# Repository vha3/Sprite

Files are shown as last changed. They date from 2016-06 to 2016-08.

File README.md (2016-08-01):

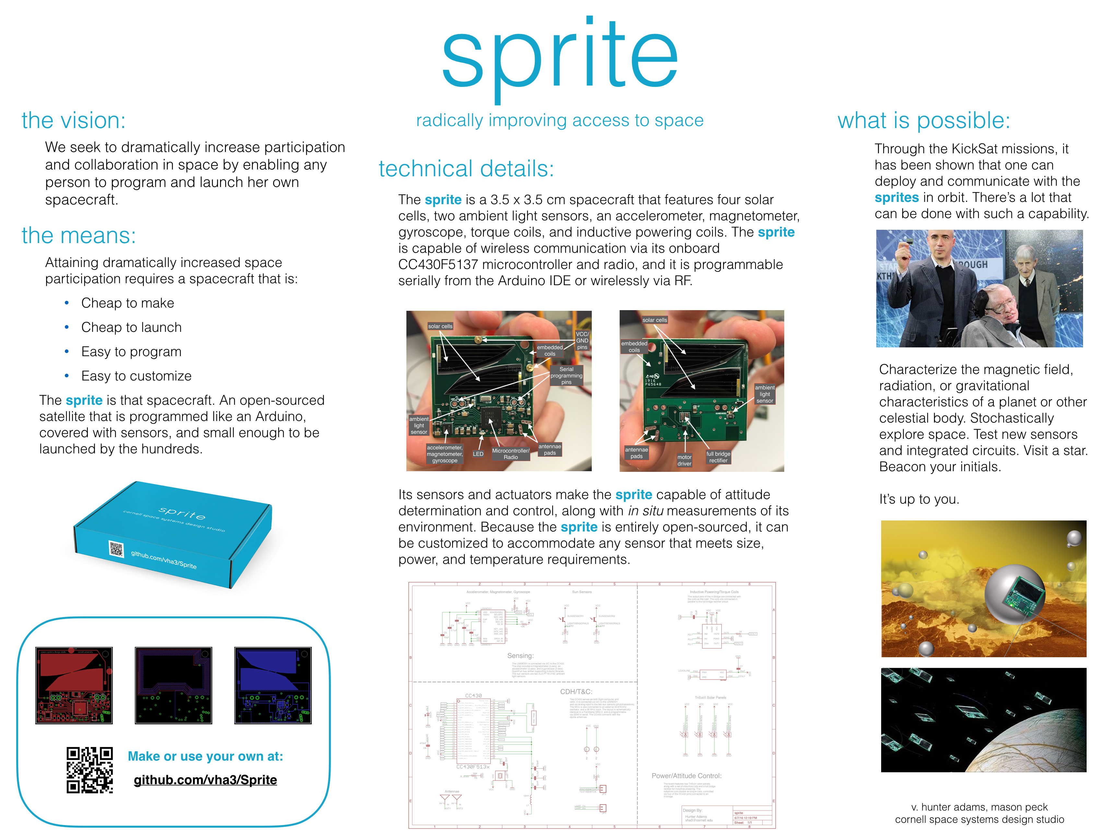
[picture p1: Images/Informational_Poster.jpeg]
My image

 The folders above include everything that you need to start using a newly purchased Sprite or to make one of your own.

 All necessary prototyping materials for programming the Sprite are included in the Sprite development kit. For those that bought or made a Sprite independently, a DigiKey cart is provided below that includes all necessary materials.

http://www.digikey.com/short/3zwh0t

##Just Bought a Sprite?
See the Sprite User's Manual in the main repository above. The manual will walk you through software installation and wiring your Sprite for programming. The Demo Software folder contains a number of Arduino sketches that exercise the Sprite's various sensors and actuators. The ReadMe within the Demo Software folder links to the panStamp example sketches folder, which contains a number more Arduino sketches that will work on the Sprite.

##Making Your Own Sprite?
The above folders contain all of the necessary files and information for having your own Sprite made by a board house. Download this repo, and send a zipped file containing the Gerbers, BOM and CPL, and the images to any board house (request a half-width board, if you intend for it to be used with the Sprite mothership deployer). You may also be interested in downloading the Eagle Cad board and schematic files to customize your own board. Both of these can be found in the Eagle folder.

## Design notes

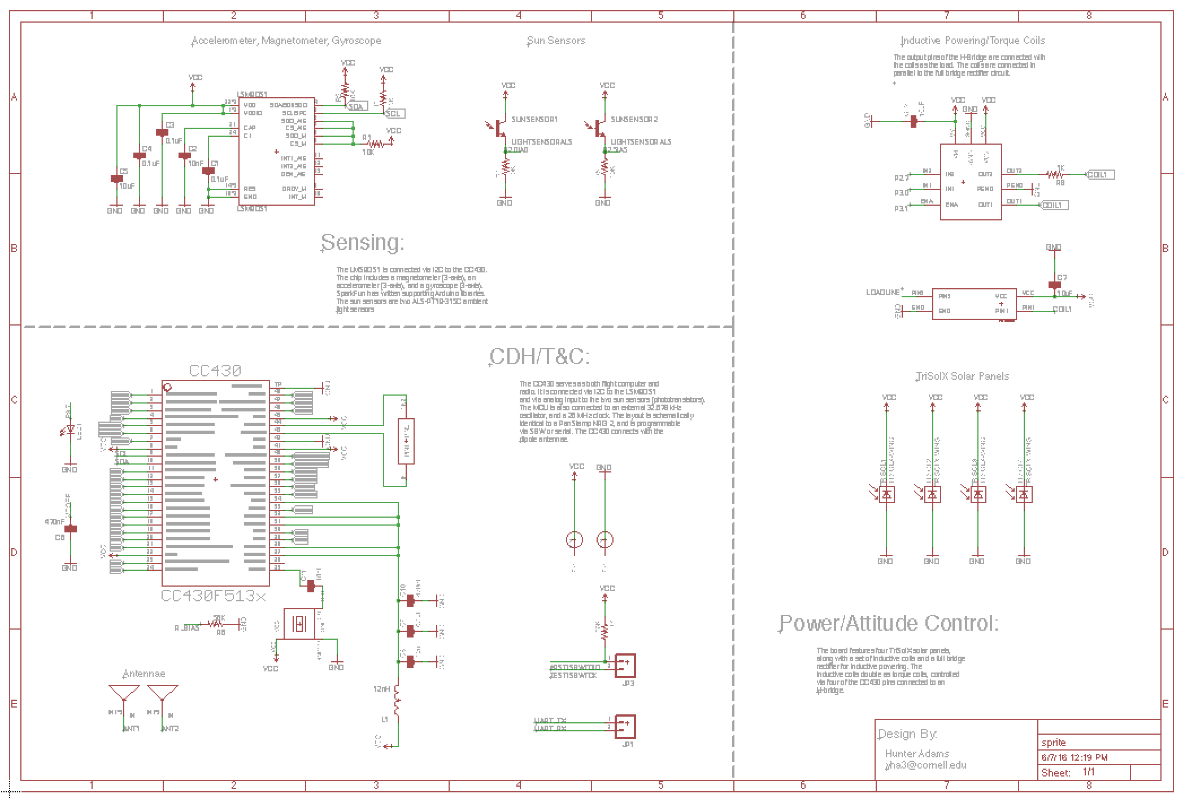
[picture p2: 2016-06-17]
Images/SCHEMATIC.png

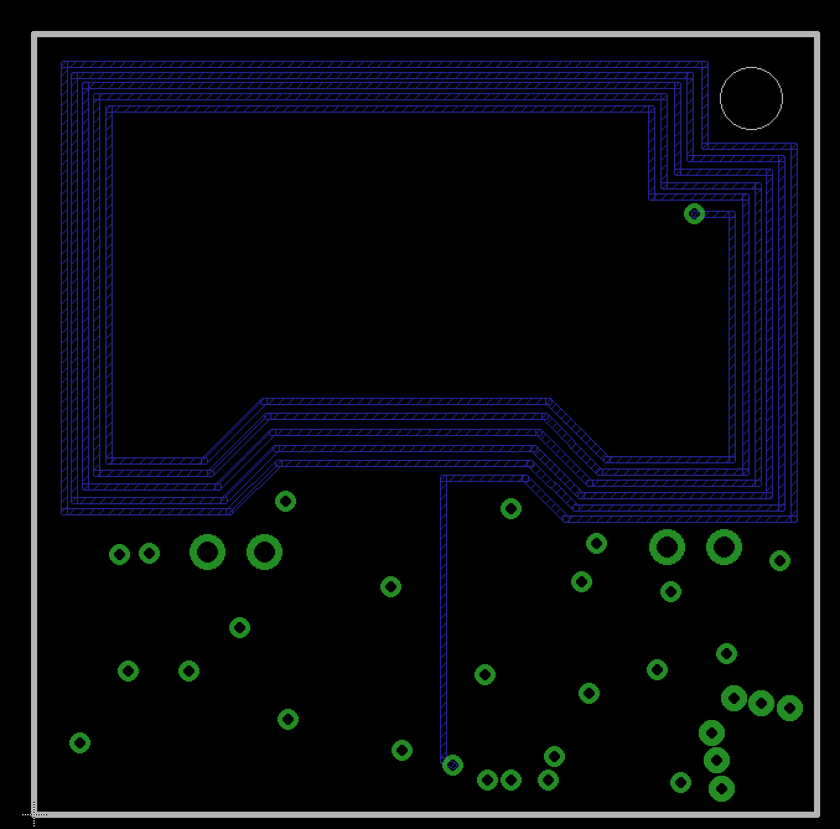
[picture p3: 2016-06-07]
Images/LAYER2.png

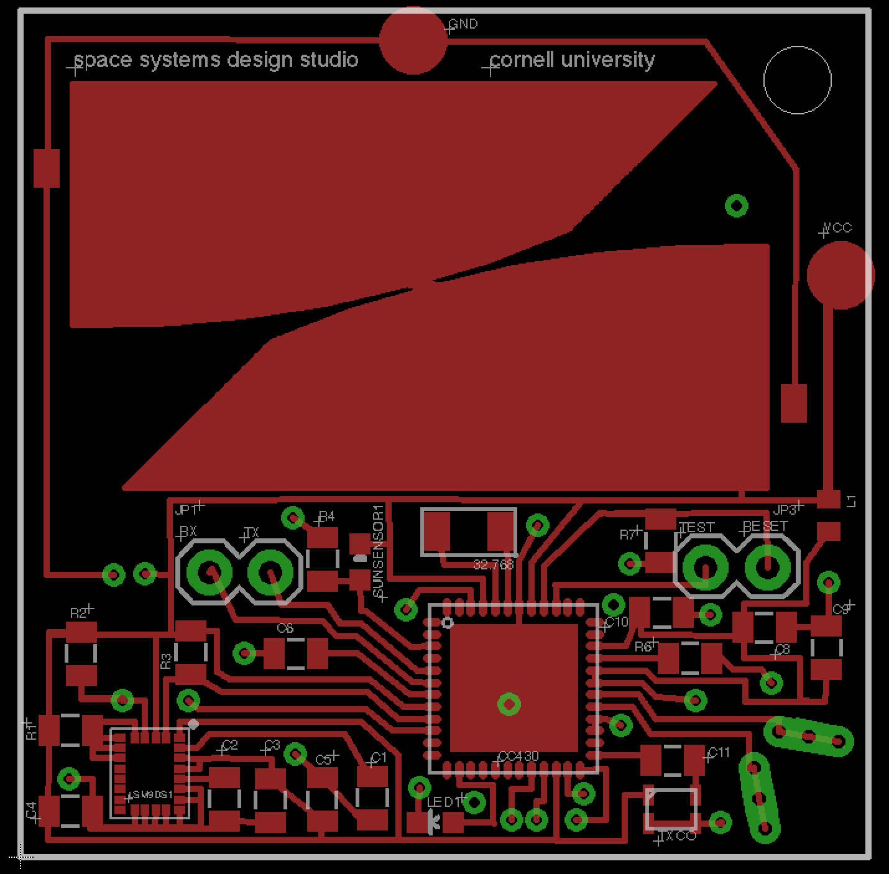
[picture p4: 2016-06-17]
Images/TOP.png

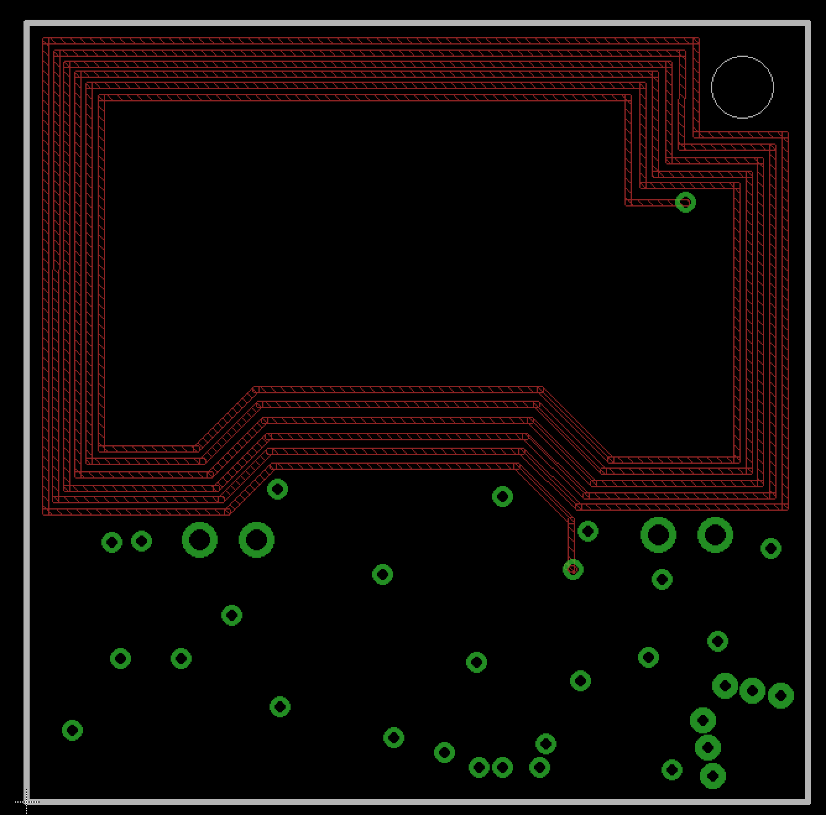
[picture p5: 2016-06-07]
Images/LAYER3.png

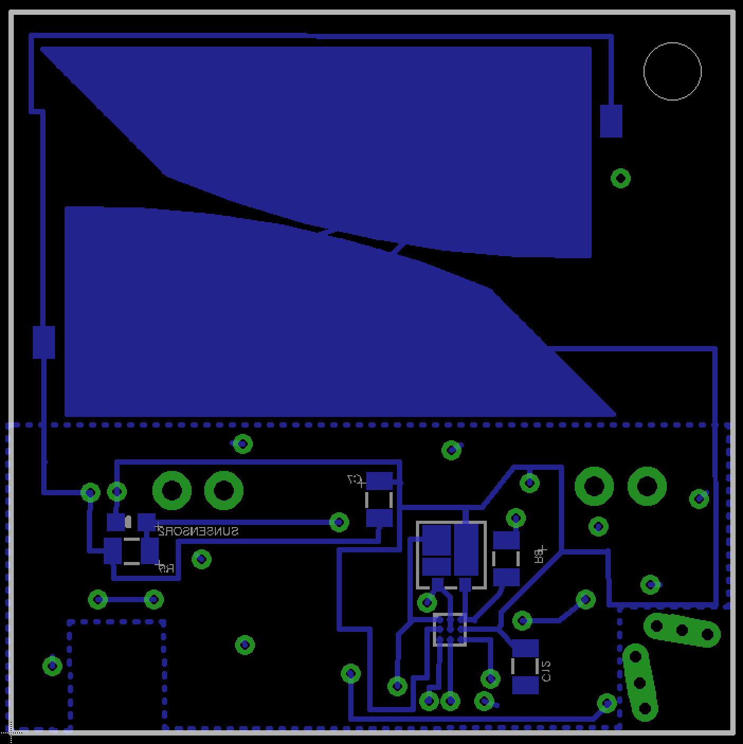
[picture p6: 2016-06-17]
Images/BOTTOM.png

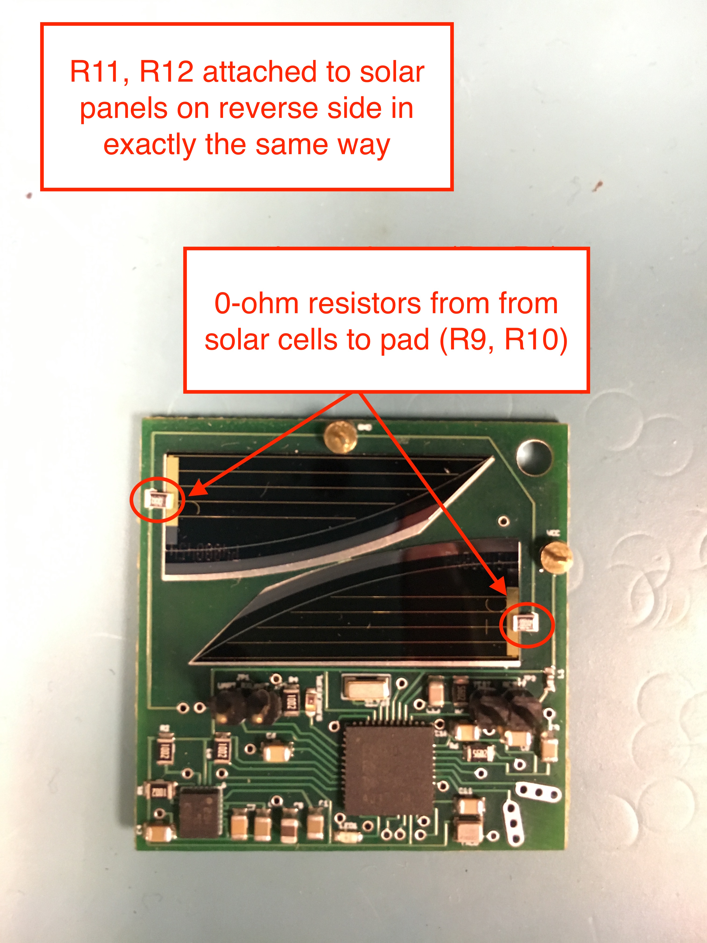
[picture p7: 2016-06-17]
Images/Image.JPG

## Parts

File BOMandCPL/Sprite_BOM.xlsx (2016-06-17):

 | Sprite Chipsat
 | Hunter Adams
 | vha3@cornell.edu
Qty | Value | Device | Package | Parts | Description | Digikey P/N | Manufacturer P/N | Manufacturer
1 | Green | LED0603 | LED-0603 | LED1 | LEDs | 475-2709-1-ND | LG L29K-G2J1-24-Z | OSRAM Opto Semiconductors Inc. (http://www.digikey.com/Suppliers/us/Osram.page?lang=en)
2 | N/A | M02PTH | 1X02 | JP1, JP3 | Header 2 | DNP | DNP | DNP
1 | 26 MHz | TCXO_7Z | TXC_7Z | TXCO | RF oscillator | 887-1622-1-ND | 7Z-26.000MDG-T | TXC Corporation
4 | 0.1uF | CAP0805 | 805 | C1, C3, C4, C9 | Capacitor | 478-3352-2-ND | 08055C104JAT2A | AVX Corp.
5 | 10K | RESISTOR0805 | 805 | R1, R2, R3, R4, R5 | Resistor | 311-10.0KCRTR-ND | RC0805FR-0710KL | Yageo
3 | 10nF | CAP0805 | 805 | C2, C8, C11 | Capacitor | 478-1383-2-ND | 08055C103KAT2A | AVX Corp.
3 | 10uF | CAP0805 | 805 | C5, C7, C12 | Capacitor | 478-5167-2-ND | 0805ZD106KAT2A | AVX Corp.
1 | 12nH | INDUCTOR0402 | C0402 | L1 | Inductors | 553-2319-2-ND | PE-0402CC120JTT | Pulse Electronics Corp.
1 | 1K | RESISTOR0805-RES | 805 | R8 | Resistor | 311-1.0KARCT-ND | RC0805JR-071KL | Yageo
2 | 470nF | CAP0805 | 805 | C6, C10 | Capacitor | 478-1403-2-ND | 0805YC474KAT2A | AVX Corp.
2 | 56K | RESISTOR0805-RES | 805 | R6, R7 | Resistor | 311-56.0KCRTR-ND | RC0805FR-0756KL | Yageo
2 | ANTENNA | ANTENNA | ANTENNA | ANTENNA1, ANTENNA2 | Antennae | DNP | DNP | DNP
1 | N/A | CC430F513X---RGZ48 | RGZ48 | CC430 | ***CC430F513X***RGZ48 ** | CC430F5137IRGZR | CC430F5137IRGZR | Texas Instruments
2 | N/A | LIGHTSENSORALS | ALS-PT19 | SUNSENSOR1, SUNSENSOR2 | Ambient Light Sensor | 1080-1244-1-ND | ALS-PT19-315C/L177/TR8 | Everlight Electronics Co. Ltd
1 | N/A | LSM9DS1 | LGA24-8X4 | LSM9DS1 | LSM9DS1 3D accelerometer, gyroscope & magnetometer | 497-14946-1-ND | LSM9DS1TR | STMicroelectronics
1 | N/A | LV8417CS | LV8417CS | H-BRIDGE | H-bridge integrated circuit | LV8417CS-TE-L-HOSCT-ND | LV8417CS-TE-L-H | ON Semiconductor
1 | N/A | NSR1030QMUTAG | NSR1030QMUTAG | RECTIFIER | Full bridge rectifier integrated circuit | NSR1030QMUTAGOSCT-ND | NSR1030QMUTAG | ON Semiconductor
1 | 32.768 KHz | SPRITECRYSTALSPRITECRYSTAL | SPRITECRYSTAL | 32KHZ | Oscillator | 478-5428-1-ND | ST3215SB32768H5HPWAA | AVX Corp./Kyocera Corp.
2 | N/A | SPRITE_PIN | SPRITE_PIN | GNDPIN, VCCPIN | Pins | ED1088CT-ND | 1508-0-57-15-00-00-03-0 | Mill-Max Manufacturing Corp.
4 | N/A | TRISOLX-WING | TRISOLX-T01 | TRISOL1, TRISOL2, TRISOL3, TRISOL4 | Solar Cells | Provided by customer | Provided by customer | Provided by customer
4 | 0 ohm | RESISTOR0805 | 805 | R9, R10, R11, R12 | 0-ohm resistors connected to solar panels | 311-0.0ARTR-ND | RC0805JR-070RL | Yageo

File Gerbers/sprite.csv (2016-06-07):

Qty | Value | Device | Package | Parts | Description | PROD_ID | VALUE
1 |  | LED0603 | LED-0603 | LED1 | LEDs
2 |  | M02PTH | 1X02 | JP1, JP3 | Header 2
1 |  | TCXO_7Z | TXC_7Z | TXCO
4 | 0.1uF | CAP0805 | 0805 | C1, C3, C4, C9 | Capacitor
5 | 10K | RESISTOR0805-RES | 0805 | R1, R2, R3, R4, R5 | Resistor
3 | 10nF | CAP0805 | 0805 | C2, C8, C11 | Capacitor
3 | 10uF | CAP0805 | 0805 | C5, C7, C12 | Capacitor
1 | 12nH | INDUCTOR0402 | C0402 | L1 | Inductors
1 | 2.7V | DIODE-ZENER3.3V | SOD-323 | D1 | Zener Diode | DIO-11284 | 3.3V
1 | 20 | RESISTOR0805-RES | 0805 | R8 | Resistor
2 | 470nF | CAP0805 | 0805 | C6, C10 | Capacitor
2 | 56K | RESISTOR0805-RES | 0805 | R6, R7 | Resistor
2 | ANTENNA | ANTENNA | ANTENNA | ANTENNA1, ANTENNA2
1 | CC430F513X---RGZ48 | CC430F513X---RGZ48 | RGZ48 | CC430 | ***CC430F513X***RGZ48 **
2 | LIGHTSENSORALS | LIGHTSENSORALS | ALS-PT19 | SUNSENSOR1, SUNSENSOR2 | Ambient Light Sensor | IC-11836
1 | LSM9DS1 | LSM9DS1 | LGA24-8X4 | LSM9DS1 | LSM9DS1 3D accelerometer, gyroscope & magnetometer | IC-12536
1 | LV8417CS | LV8417CS | LV8417CS | H-BRIDGE
1 | NSR1030QMUTAG | NSR1030QMUTAG | NSR1030QMUTAG | RECTIFIER
1 | SPRITECRYSTALSPRITECRYSTAL | SPRITECRYSTALSPRITECRYSTAL | SPRITECRYSTAL | 32KHZ
2 | SPRITE_PIN | SPRITE_PIN | SPRITE_PIN | GNDPIN, VCCPIN
4 | TRISOLX-WING | TRISOLX-WING | TRISOLX-T01 | TRISOL1, TRISOL2, TRISOL3, TRISOL4

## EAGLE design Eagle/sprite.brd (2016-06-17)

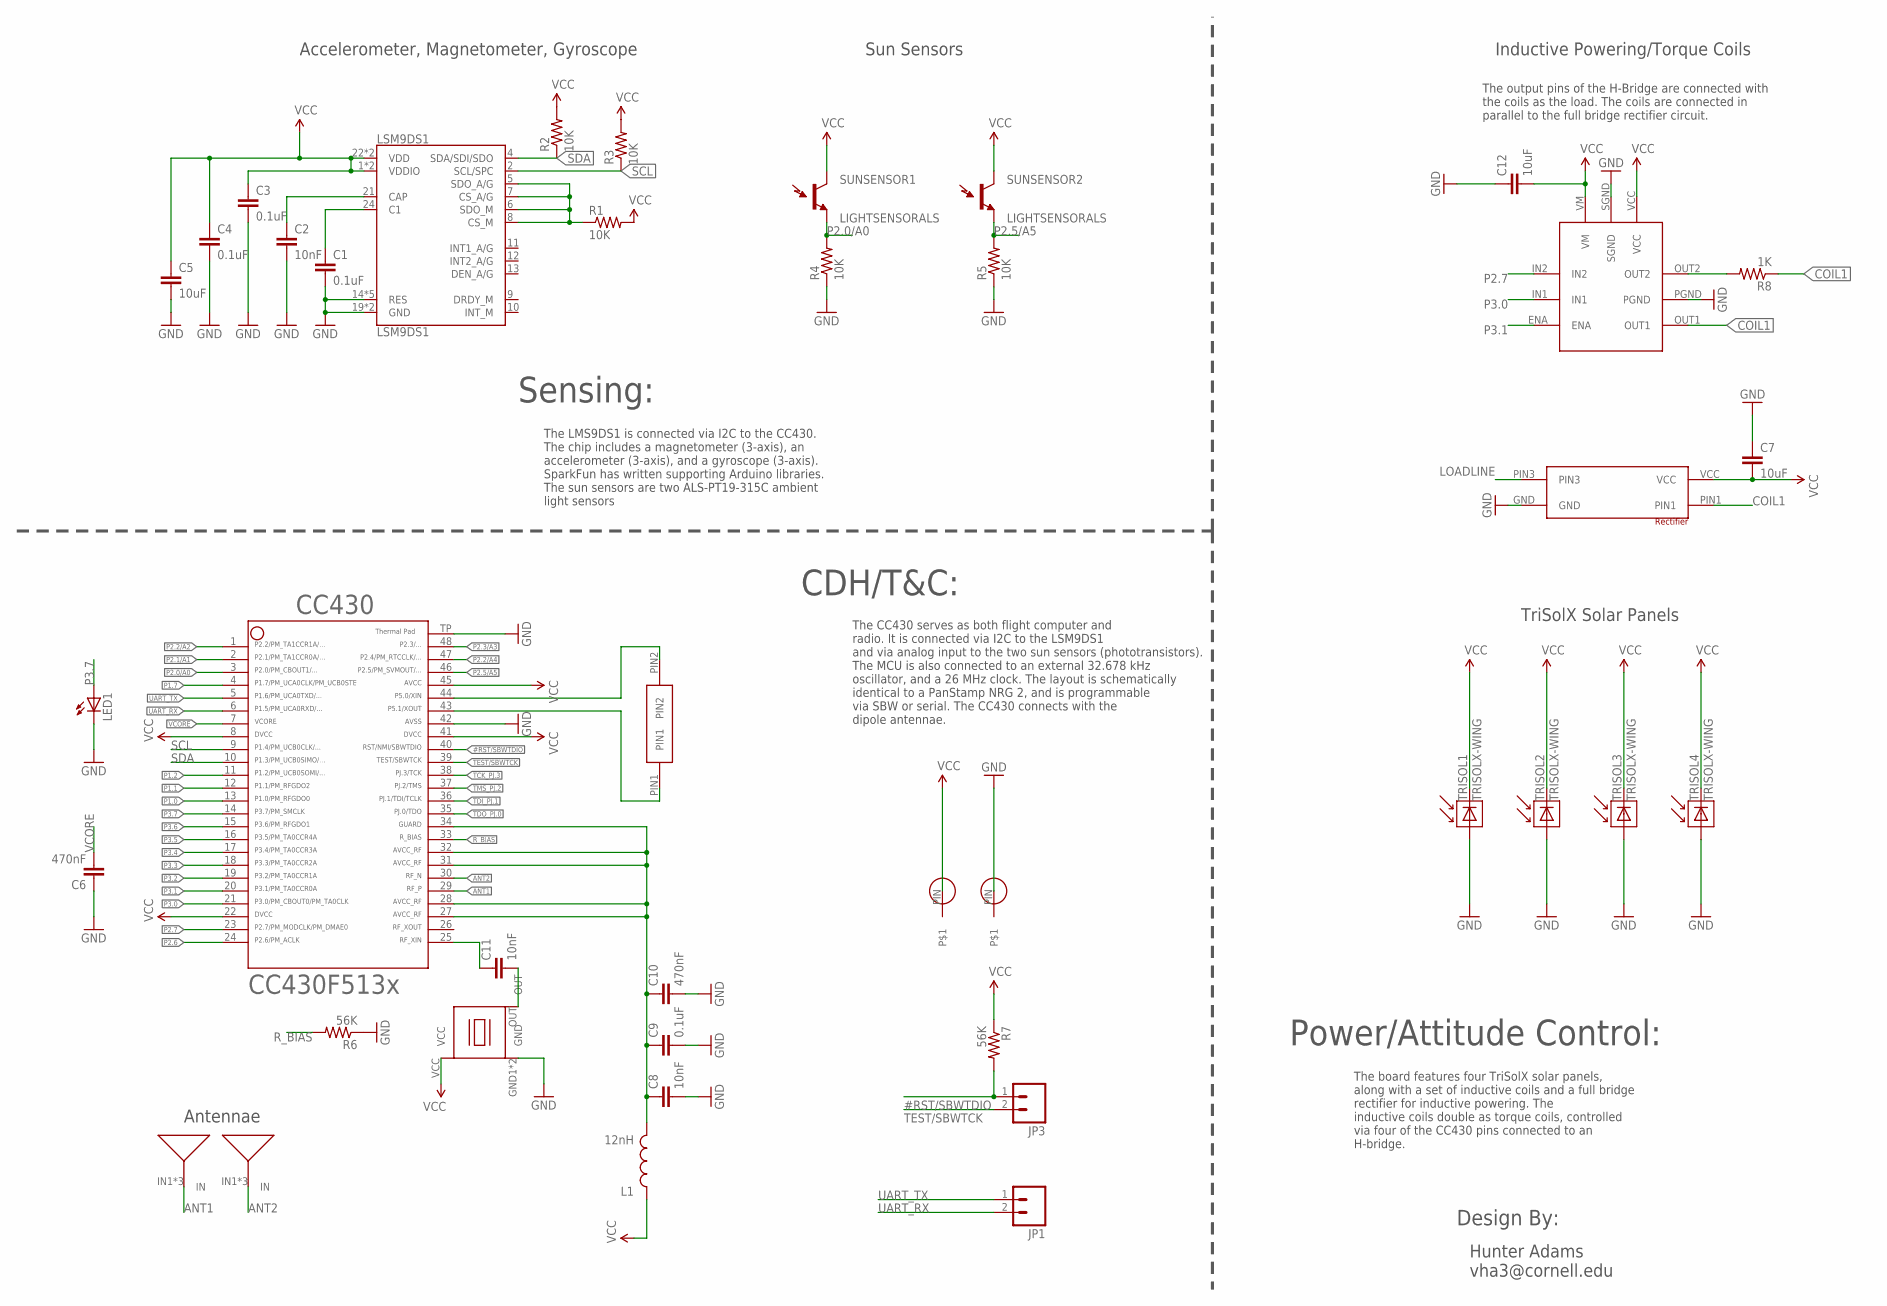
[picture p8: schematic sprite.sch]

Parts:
32KHZ: SPRITECRYSTALSPRITECRYSTAL; SPRITECRYSTAL
ANTENNA1, ANTENNA2: ANTENNA
C1, C3, C4, C9: 0.1uF; 0805
C2, C8, C11: 10nF; 0805
C5, C7, C12: 10uF; 0805
C6, C10: 470nF; 0805
CC430: CC430F513X---RGZ48; RGZ48
GNDPIN: SPRITE_PIN
H-BRIDGE: LV8417CS
JP1, JP3: M02PTH; 1X02
L1: 12nH; C0402
LED1: LED0603; LED-0603
LSM9DS1: LSM9DS1; LGA24-8X4
R1, R2, R3, R4, R5: 10K; 0805
R6, R7: 56K; 0805
R8: 1K; 0805
RECTIFIER: NSR1030QMUTAG
SUNSENSOR1, SUNSENSOR2: LIGHTSENSORALS; ALS-PT19
TRISOL1, TRISOL2, TRISOL3, TRISOL4: TRISOLX-WING; TRISOLX-T01
TXCO: TCXO_7Z; TXC_7Z
VCCPIN: SPRITE_PIN

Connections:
#RST/SBWTDIO: CC430.40, JP3.1, R7.2
ANT1: ANTENNA1.IN1, ANTENNA1.IN2, ANTENNA1.IN3, CC430.29
ANT2: ANTENNA2.IN1, ANTENNA2.IN2, ANTENNA2.IN3, CC430.30
COIL1: H-BRIDGE.OUT1, R8.1, RECTIFIER.PIN1
GND: C1.2, C2.2, C3.2, C4.2, C5.2, C6.1, C7.1, C8.2, C9.2, C10.2, C12.1, CC430.42, CC430.TP (49), GNDPIN.PIN, H-BRIDGE.PGND, H-BRIDGE.SGND, LED1.C, LSM9DS1.14 (RES), LSM9DS1.15 (RES), LSM9DS1.16 (RES), LSM9DS1.17 (RES), LSM9DS1.18 (RES), LSM9DS1.19 (GND), LSM9DS1.20 (GND), R4.1, R5.1, R6.1, RECTIFIER.GND, TRISOL1.P$3 (A), TRISOL2.P$3 (A), TRISOL3.P$3 (A), TRISOL4.P$3 (A), TXCO.GND1 (GND), TXCO.GND2 (GND)
GUARD: C8.1, C9.1, C10.1, CC430.27, CC430.28, CC430.31, CC430.32, CC430.34, L1.2
LOADLINE: H-BRIDGE.OUT2, R8.2, RECTIFIER.PIN3
unnamed: C1.1, LSM9DS1.24 (C1)
unnamed: C2.1, LSM9DS1.21 (CAP)
unnamed: LSM9DS1.5 (SDO_A/G), LSM9DS1.6 (SDO_M), LSM9DS1.7 (CS_A/G), LSM9DS1.8 (CS_M), R1.1
unnamed: C11.1, CC430.25
unnamed: C11.2, TXCO.OUT
unnamed: 32KHZ.PIN2, CC430.44
unnamed: 32KHZ.PIN1, CC430.43
P1.0: CC430.13
P1.1: CC430.12
P1.2: CC430.11
P1.7: CC430.4
P2.0/A0: CC430.3, R4.2, SUNSENSOR1.E (E1)
P2.1/A1: CC430.2
P2.2/A2: CC430.1
P2.2/A4: CC430.47
P2.3/A3: CC430.48
P2.5/A5: CC430.46, R5.2, SUNSENSOR2.E (E1)
P2.6: CC430.24
P2.7: CC430.23, H-BRIDGE.IN2
P3.0: CC430.21, H-BRIDGE.IN1
P3.1: CC430.20, H-BRIDGE.ENA
P3.2: CC430.19
P3.3: CC430.18
P3.4: CC430.17
P3.5: CC430.16
P3.6: CC430.15
P3.7: CC430.14, LED1.A
R_BIAS: CC430.33, R6.2
SCL: CC430.9, LSM9DS1.2 (SCL/SPC), R3.1
SDA: CC430.10, LSM9DS1.4 (SDA/SDI/SDO), R2.1
TCK_PJ.3: CC430.38
TDI_PJ.1: CC430.36
TDO_PJ.0: CC430.35
TEST/SBWTCK: CC430.39, JP3.2
TMS_PJ.2: CC430.37
UART_RX: CC430.6, JP1.2
UART_TX: CC430.5, JP1.1
VCC: C3.1, C4.1, C5.1, C7.2, C12.2, CC430.8, CC430.22, CC430.41, CC430.45, H-BRIDGE.VCC, H-BRIDGE.VM, L1.1, LSM9DS1.1 (VDDIO), LSM9DS1.3 (VDDIO), LSM9DS1.22 (VDD), LSM9DS1.23 (VDD), R1.2, R2.2, R3.2, R7.1, RECTIFIER.VCC, SUNSENSOR1.C (C1), SUNSENSOR2.C (C1), TRISOL1.P$2 (C), TRISOL2.P$2 (C), TRISOL3.P$2 (C), TRISOL4.P$2 (C), TXCO.VCC, VCCPIN.PIN
VCORE: C6.2, CC430.7

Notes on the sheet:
Accelerometer, Magnetometer, Gyroscope
Sun Sensors
The LMS9DS1 is connected via I2C to the CC430. The chip includes a magnetometer (3-axis), an accelerometer (3-axis), and a gyroscope (3-axis). SparkFun has written supporting Arduino libraries. The sun sensors are two ALS-PT19-315C ambient light sensors
Sensing:
CDH/T&C:
The CC430 serves as both flight computer and radio. It is connected via I2C to the LSM9DS1 and via analog input to the two sun sensors (phototransistors). The MCU is also connected to an external 32.678 kHz oscillator, and a 26 MHz clock. The layout is schematically identical to a PanStamp NRG 2, a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
Power/Attitude Control:
The board features four TriSolX solar panels, along with a set of inductive coils and a full bridge rectifier for inductive powering. The inductive coils double as torque coils, controlled via four of the CC430 pins connected to an H-bridge.
Antennae
TriSolX Solar Panels
Inductive Powering/Torque Coils
Hunter Adams vha3@cornell.edu
Design By:
The output pins of the H-Bridge are connected with the coils as the load. The coils are connected in parallel to the full bridge rectifier circuit.

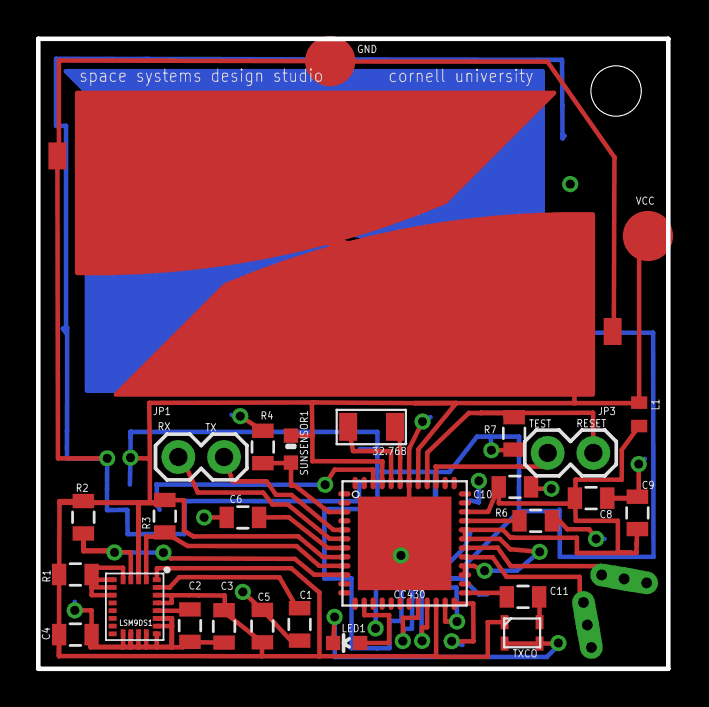
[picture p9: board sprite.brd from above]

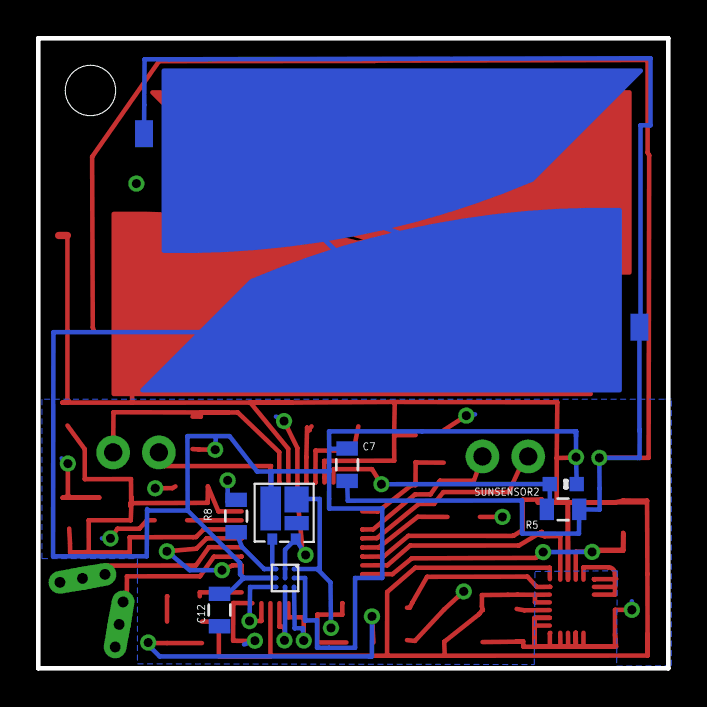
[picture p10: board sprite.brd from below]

Board: 4 copper layers, 35.0 x 35.0 mm, 40 parts (9 on the bottom side), 28 nets.

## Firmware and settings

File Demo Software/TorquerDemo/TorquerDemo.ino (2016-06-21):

/*
    smeMagnetic Library - Localization Information

    This example print the 3Axis X,Y,Z information

    created 27 May 2015
    by Seve (seve@axelelettronica.it)

    This example is in the public domain
    https://github.com/ameltech

    LSM9DS1  more information available here:
    http://www.stmicroelectronics.com.cn/web/catalog/sense_power/FM89/SC1448/SC1448/PF259998
 */
 
 /*
 Exercises the Sprite torque coils. The coils are commanded to pump
 current in the positive direction, the negative direction, and are
 commanded off. For each state, a magnetometer measurement is sent via
 serial to illustrate the effect of the torque coils.
 */

#include <Arduino.h>
#include <Wire.h>
#include "HardwareSerial.h"

#include <LSM9DS1.h>

int in2 = 15;
int in1 = 16;
int enable = 17;


// the setup function runs once when you press reset or power the board
void setup() {
    Wire.begin();
    smeMagnetic.begin();
    Serial.begin(9600);
    pinMode(in2, OUTPUT);
    pinMode(in1, OUTPUT);
    pinMode(enable, OUTPUT);
}

void printAxis(int x, int y, int z) {
    Serial.print("  X = ");
    Serial.print(x, DEC);
    Serial.print("     Y = ");
    Serial.print(y, DEC);
    Serial.print("     Z = ");
    Serial.println(z, DEC);
}

// the loop function runs over and over again forever
void loop() {

    int x = 0;
    int y = 0;
    int z = 0;

    digitalWrite(in1, LOW);
    digitalWrite(enable, LOW);
    digitalWrite(in2, HIGH);
//
    digitalWrite(LED, HIGH);
//
    delay(500);

    x = smeMagnetic.readX();
    y = smeMagnetic.readY();
    z = smeMagnetic.readZ();

    Serial.println("All Off:");
    Serial.print("Magnetometer  [mgauss]  :");
    printAxis(x, y, z);

    digitalWrite(enable, HIGH);
    digitalWrite(in1, LOW);
    digitalWrite(in2, HIGH);

    delay(500);

    x = smeMagnetic.readX();
    y = smeMagnetic.readY();
    z = smeMagnetic.readZ();

    Serial.println("First Direction:");
    Serial.print("Magnetometer  [mgauss]  :");
    printAxis(x, y, z);

    delay(500);

    x = smeMagnetic.readX();
    y = smeMagnetic.readY();
    z = smeMagnetic.readZ();

    digitalWrite(in2, LOW);
    digitalWrite(in1, HIGH);

    delay(500);

    x = smeMagnetic.readX();
    y = smeMagnetic.readY();
    z = smeMagnetic.readZ();

    Serial.println("Second Direction:");
    Serial.print("Magnetometer  [mgauss]  :");
    printAxis(x, y, z);

    digitalWrite(LED, LOW);
    delay(100);

    digitalWrite(LED, HIGH);    // turn the LED on
    delay(500);            // wait for a second

}

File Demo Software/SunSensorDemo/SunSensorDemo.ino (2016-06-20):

// Reads ambient light from front/back sensor,
// turns on LED if light is above threshold,
// turns off LED if light is below threshold

int val=0;
int back_sunsensor=13;
int front_sunsensor=8;
int newval=0;

void setup() {
  // put your setup code here, to run once:
  pinMode(LED, OUTPUT);
}

void loop() {
  val = analogRead(back_sunsensor);
//  val = analogRead(front_sunsensor);
  newval = (val/4);
  if (newval>255){
    digitalWrite(LED, HIGH);
  } else {
    digitalWrite(LED, LOW);
  }
}

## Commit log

2016-05-01 board and schematic files
    [sprite.brd, sprite.sch]
2016-05-03 added Gerbers, fixed DRC errors
    [sprite.brd, sprite.sch]
2016-05-03 zipped Gerbers and image files
    [Sprite_BOM.xlsx]
2016-05-13 added CPL document
    [Sprite_BOM.xlsx, sprite.csv, sprite_b.csv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]
2016-06-05 fixed reset line, added current-limiting resistor and bypass cap
    [Sprite_BOM.xlsx, sprite.brd, sprite.sch]
2016-06-05 added identifying silkscreen
    [sprite.brd]
2016-06-06 spaced out resistor
    [sprite.brd]
2016-06-07 updated gerbers
    [Sprite_BOM.xlsx, sprite.brd, sprite.csv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]
2016-06-07 Delete Board.png
    outdated
2016-06-07 Delete sprite_b.csv
    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
    [sprite_b.csv]
2016-06-17 cleaned up repo
    [Sprite_BOM.xlsx, sprite.brd, sprite.csv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]
2016-06-20 reorganized repo
    [Sprite_BOM.xlsx, sprite.brd, sprite.csv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]

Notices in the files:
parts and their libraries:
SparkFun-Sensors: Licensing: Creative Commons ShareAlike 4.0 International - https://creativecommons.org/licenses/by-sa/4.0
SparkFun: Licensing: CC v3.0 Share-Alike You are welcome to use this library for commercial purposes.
